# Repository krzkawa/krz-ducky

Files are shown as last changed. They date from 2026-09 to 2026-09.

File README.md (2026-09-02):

# krzducky

RP2040 hardware injection device.

## Repository Layout

* `pcb/` — KiCad schematic and board layout files also gerber files.
* `BOM.md` — Component parts list and AliExpress links.
* `firmware/` — CircuitPython and pico-ducky files.

## Hardware Specs

* **MCU:** RP2040 (QFN-56)
* **Flash:** 16MB W25Q128 (SOIC-8)
* **Power:** AP2112K-3.3 LDO (5V USB to 3.3V)
* **Passives:** 0603 size for hand-soldering / hot air assembly
* **Clock:** 12MHz 3225 crystal with 18pF load capacitors
* **Control:** Manual BOOTSEL tactile switch

## Flashing & Setup

1. Hold the **BOOTSEL** button and plug the device into a PC.
2. Drag `firmware/adafruit-circuitpython-*.uf2` onto the mounted `RPI-RP2` drive.
3. Once it reboots as `CIRCUITPY`, copy all files from `firmware/pico-ducky/` to the root of the `CIRCUITPY` drive.
4. Edit or create `payload.dd` on the drive with your DuckyScript commands.

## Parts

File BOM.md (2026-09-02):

# Bill of Materials (BOM) — RP2040 Rubber Ducky

---

### Integrated Circuits & Core Components

| RefDes | Qty | Component / Description | Package | AliExpress Search Link |
|---|---|---|---|---|
| **U1** | 1 | RP2040 Microcontroller | QFN-56 (7x7mm) | [Search RP2040 QFN-56](https://www.aliexpress.com/w/wholesale-RP2040-QFN%25252d56.html) |
| **U2** | 1 | AP2112K-3.3 Voltage Regulator (3.3V 600mA LDO) | SOT-23-5 | [Search AP2112K-3.3 SOT-23-5](https://www.aliexpress.com/w/wholesale-AP2112K%25252d3.3-SOT23%25252d5.html) |
| **U3** | 1 | W25Q128JVSIC Flash Memory (16MB NOR Flash) | SOIC-8 (208mil) | [Search W25Q128JVSIC SOIC-8](https://www.aliexpress.com/w/wholesale-W25Q128JVSIC-SOIC8.html) |
| **Y1** | 1 | 12MHz SMD Crystal (12pF, 4-pin) | 3225 (3.2x2.5mm) | [Search 12MHz SMD Crystal 3225](https://www.aliexpress.com/w/wholesale-12MHz-SMD-Crystal-3225.html) |
| **SW1** | 1 | Tactile Push Button (BOOTSEL) | 3x4mm / 2-pin SMD | [Search 3x4mm SMD Tactile Switch](https://www.aliexpress.com/w/wholesale-3x4mm-SMD-Tactile-Switch.html) |
| **J1** | 1 | USB-A Male Plug Connector | Male PCB SMD Edge | [Search USB A Male SMD Connector](https://www.aliexpress.com/w/wholesale-USB-A-Male-SMD-Connector.html) |

---

### Resistors (0603 SMD)

| RefDes | Qty | Value | Tolerance | Package | AliExpress Search Link |
|---|---|---|---|---|---|
| **R1, R2** | 2 | 27 Ω | ±1% | 0603 | [Search 27 Ohm 0603 Resistor](https://www.aliexpress.com/w/wholesale-27-Ohm-0603-Resistor.html) |
| **R3** | 1 | 1 kΩ | ±1% | 0603 | [Search 1k Ohm 0603 Resistor](https://www.aliexpress.com/w/wholesale-1k-Ohm-0603-Resistor.html) |
| **R4** | 1 | 10 kΩ | ±1% | 0603 | [Search 10k Ohm 0603 Resistor](https://www.aliexpress.com/w/wholesale-10k-Ohm-0603-Resistor.html) |

---

### Capacitors (0603 SMD)

| RefDes | Qty | Value | Voltage | Package | AliExpress Search Link |
|---|---|---|---|---|---|
| **C1, C2** | 2 | 10 µF | 16V (X5R/X7R) | 0603 | [Search 10uF 0603 Capacitor](https://www.aliexpress.com/w/wholesale-10uF-0603-Capacitor.html) |
| **C3–C7** | 5 | 100 nF | 16V (X7R) | 0603 | [Search 100nF 0603 Capacitor](https://www.aliexpress.com/w/wholesale-100nF-0603-Capacitor.html) |
| **C8, C9** | 2 | 18 pF | 50V (C0G/NP0) | 0603 | [Search 18pF 0603 Capacitor](https://www.aliexpress.com/w/wholesale-18pF-0603-Capacitor.html) |
| **C10** | 1 | 1 µF | 16V (X7R) | 0603 | [Search 1uF 0603 Capacitor](https://www.aliexpress.com/w/wholesale-1uF-0603-Capacitor.html) |

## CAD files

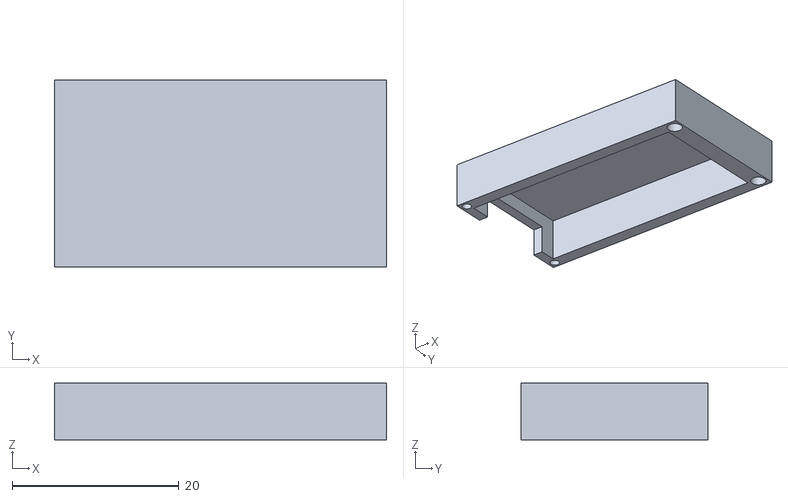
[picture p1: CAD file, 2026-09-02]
cad/ducky-case-top.stl
39.8 x 22.5 x 6.80

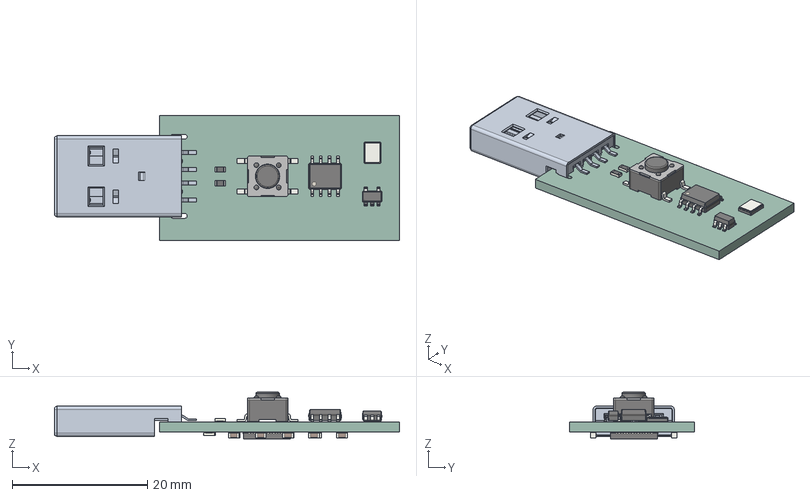
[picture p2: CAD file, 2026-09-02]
cad/pcb-ducky.step
51.0 x 18.5 x 6.88 mm
R_0603_1608Metric x 4
SOIC-8_3.9x4.9mm_P1.27mm
SOT-23-5
Crystal_SMD_3225-4Pin_3.2x2.5mm
SW_SPST_PTS645Sx43SMTR92
C_0603_1608Metric x 10
QFN-56-1EP_7x7mm_P0.4mm_EP3.2x3.2mm
krzducky-unsaved-export-CidLQf_PCB

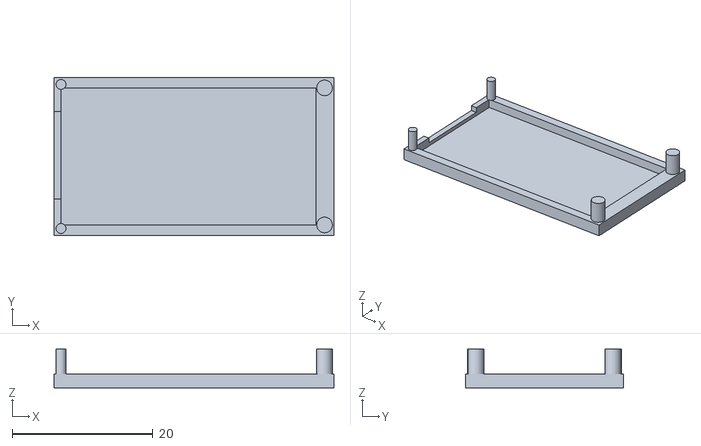
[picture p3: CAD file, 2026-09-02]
cad/ducky-case-bottom.stl
39.8 x 22.5 x 5.50

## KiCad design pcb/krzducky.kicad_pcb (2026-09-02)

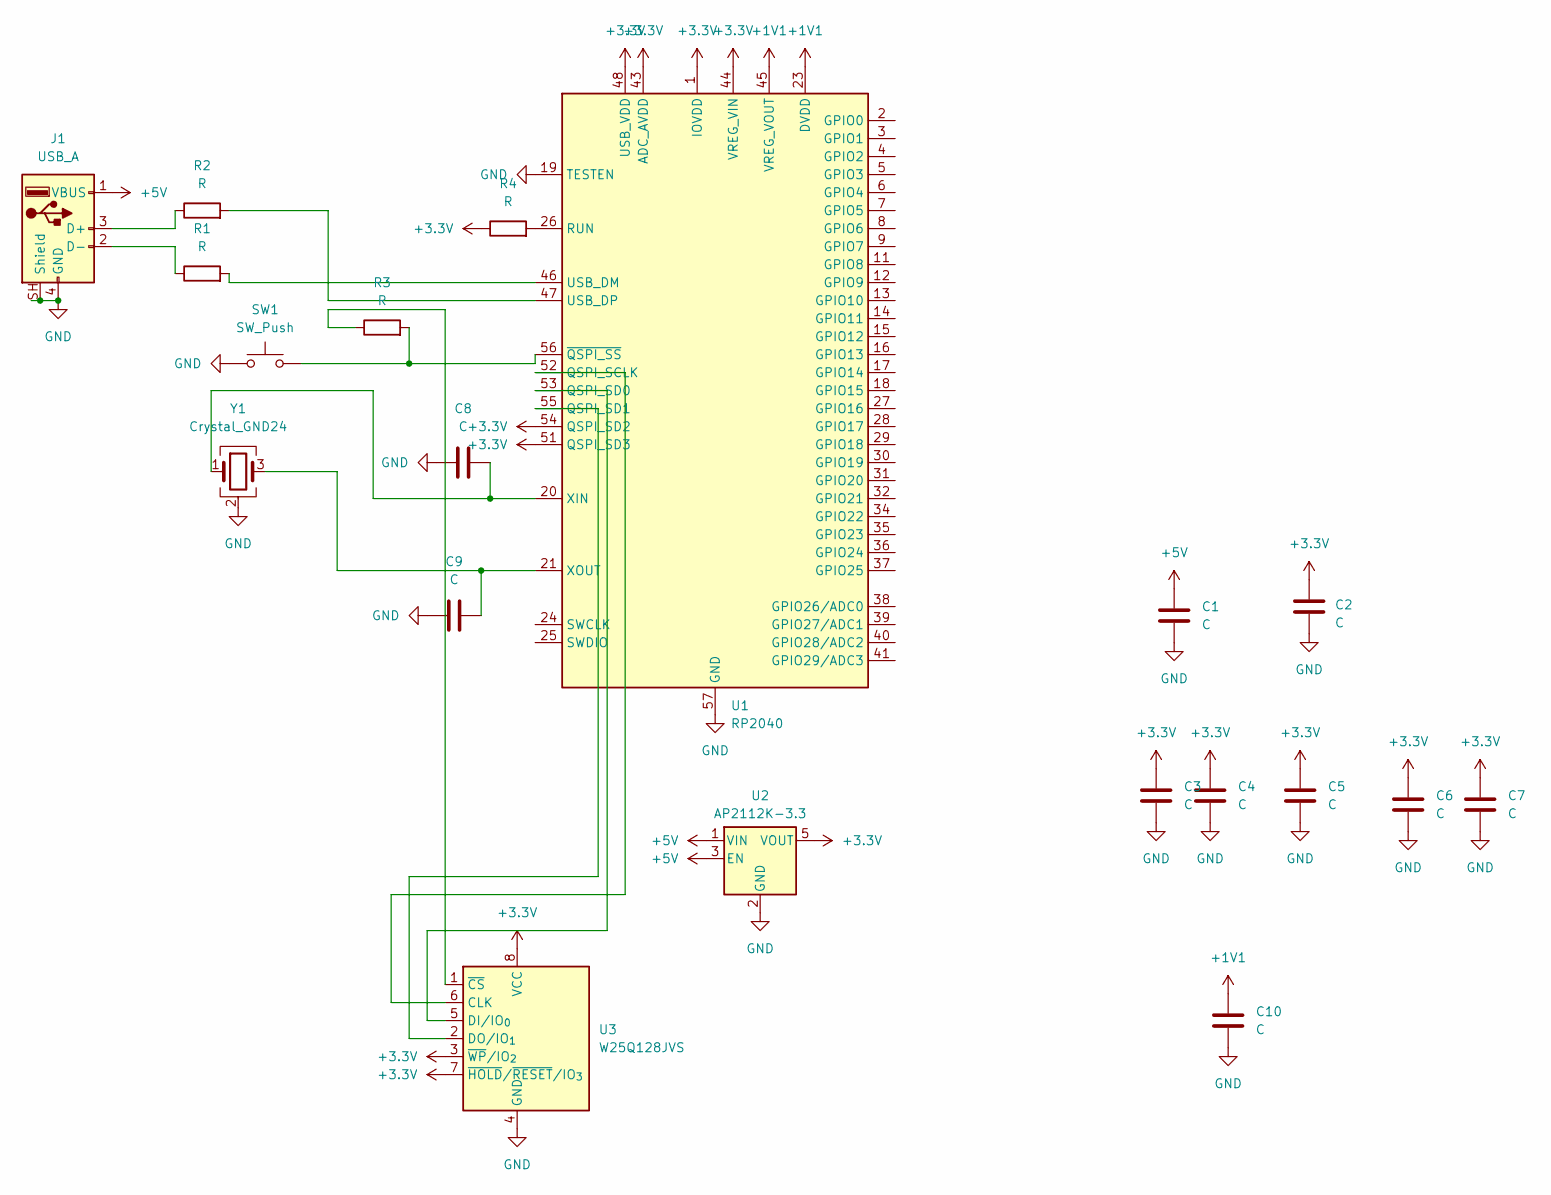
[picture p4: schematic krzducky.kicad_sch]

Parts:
C1, C2, C3, C4, C5, C6, C7, C8, C9, C10: C; C_0603_1608Metric_Pad1.08x0.95mm_HandSolder
J1: USB_A; USB_A_Molex_48037-2200_Horizontal
R1, R2, R3, R4: R; R_0603_1608Metric_Pad0.98x0.95mm_HandSolder
SW1: SW_Push; SW_SPST_PTS645Sx43SMTR92
U1: RP2040; QFN-56-1EP_7x7mm_P0.4mm_EP3.2x3.2mm
U2: AP2112K-3.3; SOT-23-5_HandSoldering
U3: W25Q128JVS; SOIC-8_3.9x4.9mm_P1.27mm
Y1: Crystal_GND24; Crystal_SMD_3225-4Pin_3.2x2.5mm_HandSoldering

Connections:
+1V1: C10.1, U1.23 (DVDD), U1.45 (VREG_VOUT), U1.50 (DVDD)
+3.3V: C2.1, C3.1, C4.1, C5.1, C6.1, C7.1, R4.1, U1.1 (IOVDD), U1.10 (IOVDD), U1.22 (IOVDD), U1.33 (IOVDD), U1.42 (IOVDD), U1.43 (ADC_AVDD), U1.44 (VREG_VIN), U1.48 (USB_VDD), U1.49 (IOVDD), U1.51 (QSPI_SD3), U1.54 (QSPI_SD2), U2.5 (VOUT), U3.3 (~WP/IO_{2}), U3.7 (~HOLD/~RESET/IO_{3}), U3.8 (VCC)
+5V: C1.1, J1.1 (VBUS), U2.1 (VIN), U2.3 (EN)
GND: C1.2, C2.2, C3.2, C4.2, C5.2, C6.2, C7.2, C8.1, C9.1, C10.2, J1.4 (GND), J1.SH (Shield), SW1.1, U1.19 (TESTEN), U1.57 (GND), U2.2 (GND), U3.4 (GND), Y1.2 (G), Y1.4 (G)
unnamed: J1.3 (D+), R2.1
unnamed: J1.2 (D-), R1.1
unnamed: U1.52 (QSPI_SCLK), U3.6 (CLK)
unnamed: U1.53 (QSPI_SD0), U3.5 (DI/IO_{0})
unnamed: U1.55 (QSPI_SD1), U3.2 (DO/IO_{1})
unnamed: R4.2, U1.26 (RUN)
unnamed: R1.2, U1.46 (USB_DM)
unnamed: R2.2, U1.47 (USB_DP)
unnamed: C8.2, U1.20 (XIN), Y1.1
unnamed: C9.2, U1.21 (XOUT), Y1.3
unnamed: R3.2, SW1.2, U1.56 (~QSPI_SS)
unnamed: R3.1, U3.1 (~CS)

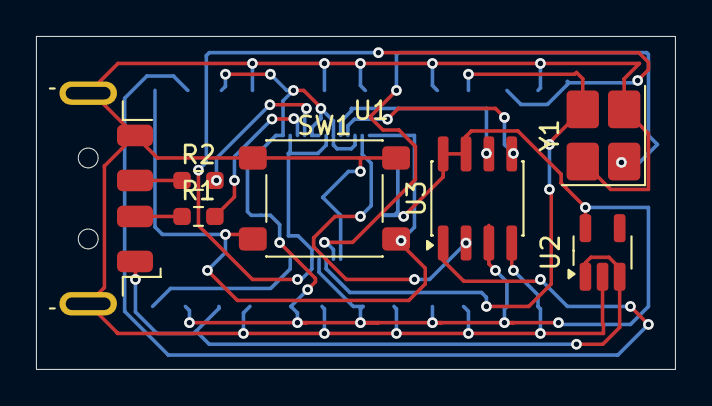
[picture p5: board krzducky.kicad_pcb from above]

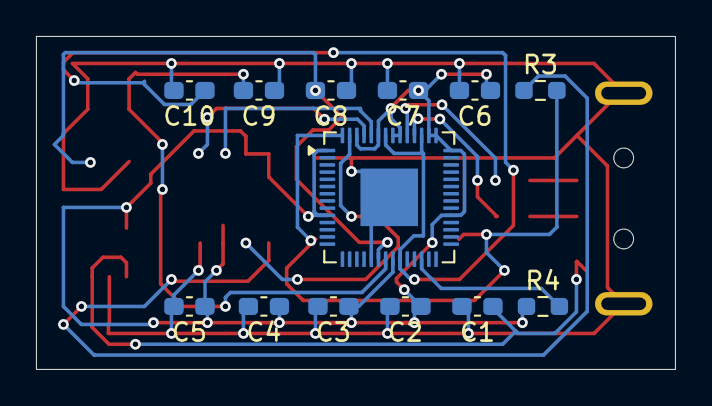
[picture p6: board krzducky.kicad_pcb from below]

Board: 2 copper layers, 35.5 x 18.5 mm, 20 parts (13 on the bottom side), 16 nets.

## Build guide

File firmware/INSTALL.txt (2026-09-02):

## Install

Install and have your USB Rubber Ducky working in less than 5 minutes.

1. Plug the device into a USB port while holding BOOTSEL. It will show up as a removable media device named `RPI-RP2`.

2. If using a Pico board:<br>
Copy the `adafruit-circuitpython-raspberry_pi_pico-en_US-10.0.3.uf2` file to the root of the Pico (`RPI-RP2`). The device will reboot and after a second or so, it will reconnect as `CIRCUITPY`.<br>
If using a Pico W board:<br>
Copy the `adafruit-circuitpython-raspberry_pi_pico_w-en_US-10.0.3.uf2` file to the root of the Pico (`RPI-RP2`). The device will reboot and after a second or so, it will reconnect as `CIRCUITPY`.
If using a Pico 2 board:<br>
Copy the `adafruit-circuitpython-raspberry_pi_pico2-en_US-10.0.3.uf2` file to the root of the Pico (`RPI-RP2`). The device will reboot and after a second or so, it will reconnect as `CIRCUITPY`.<br>
If using a Pico 2W board:<br>
Copy the `adafruit-circuitpython-raspberry_pi_pico2_w-en_US-10.0.3.uf2` file to the root of the Pico (`RPI-RP2`). The device will reboot and after a second or so, it will reconnect as `CIRCUITPY`.

3. Copy the lib folder to the root of the `CIRCUITPY`

4. Copy `*.py` to the root of the `CIRCUITPY`

5. Follow the instructions in README.md to enter setup mode

6. Copy your payload as `payload.dd` to the root of the `CIRCUITPY`

7. Unplug the device from the USB port and remove the setup jumper.

8. Enjoy your Pico-Ducky.

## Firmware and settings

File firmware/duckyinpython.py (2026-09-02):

# License : GPLv2.0
# copyright (c) 2023  Dave Bailey
# Author: Dave Bailey (dbisu, @daveisu)
#
#  TODO: ADD support for the following:
# Add jitter
# Add LED functionality
import re
import time
import random
import digitalio
from digitalio import DigitalInOut, Pull
from adafruit_debouncer import Debouncer
import board
from board import *
import asyncio
import usb_hid
from adafruit_hid.keyboard import Keyboard
from adafruit_hid.consumer_control import ConsumerControl
from adafruit_hid.consumer_control_code import ConsumerControlCode
from pins import *

# comment out these lines for non_US keyboards
from adafruit_hid.keyboard_layout_us import KeyboardLayoutUS as KeyboardLayout
from adafruit_hid.keycode import Keycode

# uncomment these lines for non_US keyboards
# replace LANG with appropriate language
#from keyboard_layout_win_LANG import KeyboardLayout as KeyboardLayout
#from keycode_win_LANG import Keycode

def _capsOn():
    return kbd.led_on(Keyboard.LED_CAPS_LOCK)

def _numOn():
    return kbd.led_on(Keyboard.LED_NUM_LOCK)

def _scrollOn():
    return kbd.led_on(Keyboard.LED_SCROLL_LOCK)

def pressLock(key):
    kbd.press(key)
    kbd.release(key)

def SaveKeyboardLedState():
    variables["$_INITIAL_SCROLLLOCK"] = _scrollOn()
    variables["$_INITIAL_NUMLOCK"] = _numOn()
    variables   ["$_INITIAL_CAPSLOCK"] = _capsOn()


def RestoreKeyboardLedState():
    if(variables["$_INITIAL_CAPSLOCK"] != _capsOn()):
        pressLock(Keycode.CAPS_LOCK)
    if(variables["$_INITIAL_NUMLOCK"] != _numOn()):
        pressLock(Keycode.NUM_LOCK)
    if(variables["$_INITIAL_SCROLLLOCK"] != _scrollOn()):
        pressLock(Keycode.SCROLL_LOCK)

duckyKeys = {
    'WINDOWS': Keycode.GUI, 'RWINDOWS': Keycode.RIGHT_GUI, 'GUI': Keycode.GUI, 'RGUI': Keycode.RIGHT_GUI, 'COMMAND': Keycode.GUI, 'RCOMMAND': Keycode.RIGHT_GUI,
    'APP': Keycode.APPLICATION, 'MENU': Keycode.APPLICATION, 'SHIFT': Keycode.SHIFT, 'RSHIFT': Keycode.RIGHT_SHIFT,
    'ALT': Keycode.ALT, 'RALT': Keycode.RIGHT_ALT, 'OPTION': Keycode.ALT, 'ROPTION': Keycode.RIGHT_ALT, 'CONTROL': Keycode.CONTROL, 'CTRL': Keycode.CONTROL, 'RCTRL': Keycode.RIGHT_CONTROL,
    'DOWNARROW': Keycode.DOWN_ARROW, 'DOWN': Keycode.DOWN_ARROW, 'LEFTARROW': Keycode.LEFT_ARROW,
    'LEFT': Keycode.LEFT_ARROW, 'RIGHTARROW': Keycode.RIGHT_ARROW, 'RIGHT': Keycode.RIGHT_ARROW,
    'UPARROW': Keycode.UP_ARROW, 'UP': Keycode.UP_ARROW, 'BREAK': Keycode.PAUSE,
    'PAUSE': Keycode.PAUSE, 'CAPSLOCK': Keycode.CAPS_LOCK, 'DELETE': Keycode.DELETE,
    'END': Keycode.END, 'ESC': Keycode.ESCAPE, 'ESCAPE': Keycode.ESCAPE, 'HOME': Keycode.HOME,
    'INSERT': Keycode.INSERT, 'NUMLOCK': Keycode.KEYPAD_NUMLOCK, 'PAGEUP': Keycode.PAGE_UP,
    'PAGEDOWN': Keycode.PAGE_DOWN, 'PRINTSCREEN': Keycode.PRINT_SCREEN, 'ENTER': Keycode.ENTER,
    'SCROLLLOCK': Keycode.SCROLL_LOCK, 'SPACE': Keycode.SPACE, 'TAB': Keycode.TAB,
    'BACKSPACE': Keycode.BACKSPACE,
    'A': Keycode.A, 'B': Keycode.B, 'C': Keycode.C, 'D': Keycode.D, 'E': Keycode.E,
    'F': Keycode.F, 'G': Keycode.G, 'H': Keycode.H, 'I': Keycode.I, 'J': Keycode.J,
    'K': Keycode.K, 'L': Keycode.L, 'M': Keycode.M, 'N': Keycode.N, 'O': Keycode.O,
    'P': Keycode.P, 'Q': Keycode.Q, 'R': Keycode.R, 'S': Keycode.S, 'T': Keycode.T,
    'U': Keycode.U, 'V': Keycode.V, 'W': Keycode.W, 'X': Keycode.X, 'Y': Keycode.Y,
    'Z': Keycode.Z, 'F1': Keycode.F1, 'F2': Keycode.F2, 'F3': Keycode.F3,
    'F4': Keycode.F4, 'F5': Keycode.F5, 'F6': Keycode.F6, 'F7': Keycode.F7,
    'F8': Keycode.F8, 'F9': Keycode.F9, 'F10': Keycode.F10, 'F11': Keycode.F11,
    'F12': Keycode.F12, 'F13': Keycode.F13, 'F14': Keycode.F14, 'F15': Keycode.F15,
    'F16': Keycode.F16, 'F17': Keycode.F17, 'F18': Keycode.F18, 'F19': Keycode.F19,
    'F20': Keycode.F20, 'F21': Keycode.F21, 'F22': Keycode.F22, 'F23': Keycode.F23,
    'F24': Keycode.F24
}
duckyConsumerKeys = {
    'MK_VOLUP': ConsumerControlCode.VOLUME_INCREMENT, 'MK_VOLDOWN': ConsumerControlCode.VOLUME_DECREMENT, 'MK_MUTE': ConsumerControlCode.MUTE,
    'MK_NEXT': ConsumerControlCode.SCAN_NEXT_TRACK, 'MK_PREV': ConsumerControlCode.SCAN_PREVIOUS_TRACK,
    'MK_PP': ConsumerControlCode.PLAY_PAUSE, 'MK_STOP': ConsumerControlCode.STOP
}

variables = {"$_RANDOM_MIN": 0, "$_RANDOM_MAX": 65535,"$_EXFIL_MODE_ENABLED": False,"$_EXFIL_LEDS_ENABLED": False,"$_INITIAL_SCROLLLOCK": False, "$_INITIAL_NUMLOCK": False, "$_INITIAL_CAPSLOCK": False}
internalVariables = {"$_CAPSLOCK_ON": _capsOn, "$_NUMLOCK_ON": _numOn, "$_SCROLLLOCK_ON": _scrollOn}
defines = {}
functions = {}

letters = "abcdefghijklmnopqrstuvwxyz"
numbers = "0123456789"
specialChars = "!@#$%^&*()"

class IF:
    def __init__(self, condition, codeIter):
        self.condition = condition
        self.codeIter = list(codeIter)
        self.lastIfResult = None
    
    def _exitIf(self):
        _depth = 0
        for line in self.codeIter:
            line = self.codeIter.pop(0)
            line = line.strip()
            if line.upper().startswith("END_IF"):
                _depth -= 1
            elif line.upper().startswith("IF"):
                _depth += 1
            if _depth < 0:
                print("No else, exiting" + str(list(self.codeIter)))
                break
        return(self.codeIter)

    def runIf(self):
        if isinstance(self.condition, str):
            self.lastIfResult = evaluateExpression(self.condition)
        elif isinstance(self.condition, bool):
            self.lastIfResult = self.condition
        else:
            raise ValueError("Invalid condition type")

        # print(f"condition {self.condition} result is {self.lastIfResult} since \"$VAR\" is {variables["$VAR"]}, code is {self.codeIter}")
        depth = 0
        for line in self.codeIter:
            line = self.codeIter.pop(0)
            line = line.strip()
            if line == "":
                continue
            # print(line)

            if line.startswith("IF"):
                depth += 1
            elif line.startswith("END_IF"):
                if depth == 0:
                    return(self.codeIter, -1)
                depth -=1
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

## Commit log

2026-09-02 Add Bill of Materials for RP2040 Rubber Ducky
    Added a comprehensive Bill of Materials (BOM) for the RP2040 Rubber Ducky project, including details for integrated circuits, resistors, and capacitors.
2026-09-02 Initial commit: Schematic, BOM, and footprint mappings
    [krzducky.kicad_pcb, krzducky.kicad_sch]
2026-09-02 add micropython and pico ducky
2026-09-02 add cad case files
    [ducky-case-bottom.stl, ducky-case-top.stl, krzducky.kicad_pcb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]
